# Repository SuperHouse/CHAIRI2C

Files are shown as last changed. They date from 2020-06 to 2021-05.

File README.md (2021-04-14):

Chair I2C Interface
===================
Copyright 2020 SuperHouse Automation Pty Ltd <www.superhouse.tv>  
Designed by Jonathan Oxer

Connects to a Permobil electric wheelchair controller, and emulates the
signals from a wheelchair joystick so that the chair can be controlled
electronically. Provides an I2C interface for connection to a host
microcontroller.

Also exposes the "5th Button" and 12V 100mA chair power connections.

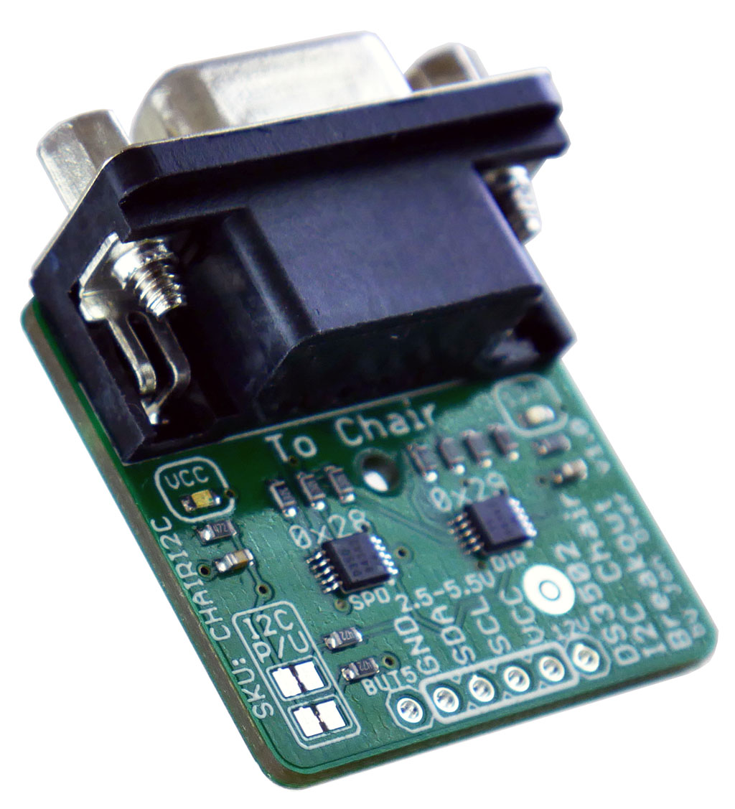
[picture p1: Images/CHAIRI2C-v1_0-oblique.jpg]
PCB


Features:

 * 1 x chair controller output.
 * I2C interface.
 * Derives 12V power from the host wheelchair controller.
 * Requires 2.7-5.5V external logic power.

More information is available at:

  http://www.superhouse.tv/chairi2c

INSTALLATION
------------
The design is saved as an EAGLE project. EAGLE PCB design software is
available from www.cadsoftusa.com free for non-commercial use. To use
this project download it and place the directory containing these files
into the "eagle" directory on your computer. Then open EAGLE and
navigate to the project.

DISTRIBUTION
------------
The specific terms of distribution of this project are governed by the
license referenced below.

LICENSE
-------
Licensed under the TAPR Open Hardware License (www.tapr.org/OHL).
The "license" folder within this repository also contains a copy of
this license in plain text format.

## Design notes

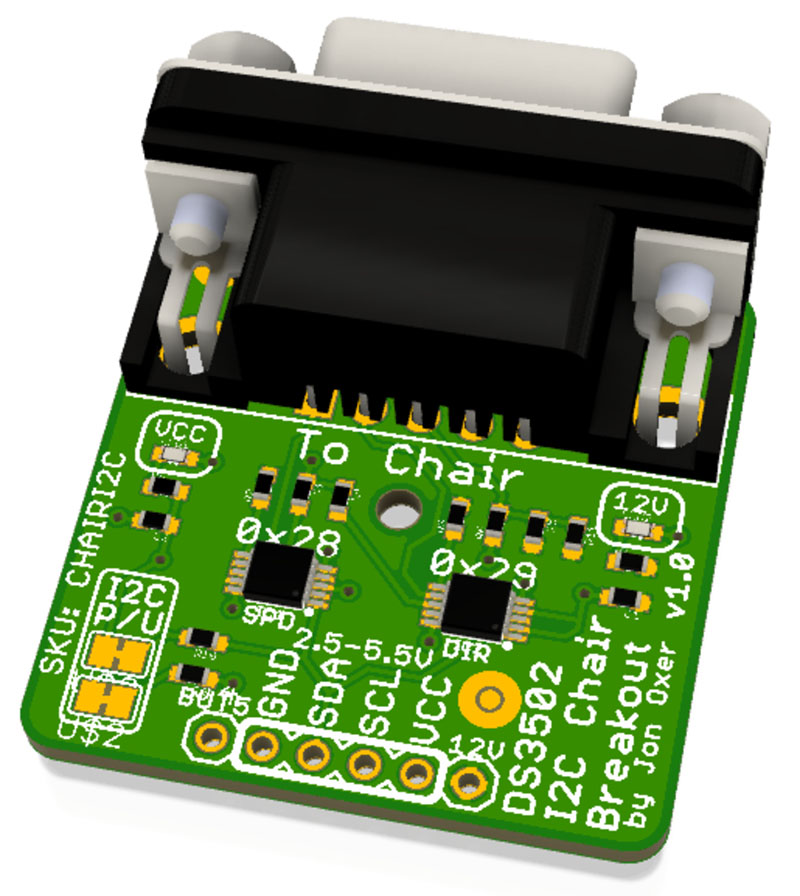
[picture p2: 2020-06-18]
Images/CHAIRI2C-v1_0-oblique-render.jpg

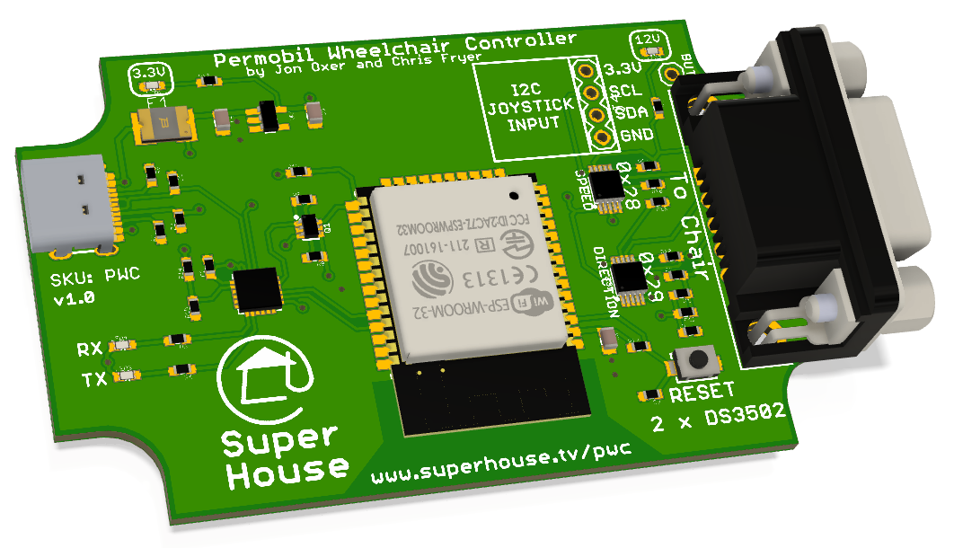
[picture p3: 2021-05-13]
Images/PWC-v1_0-render.png

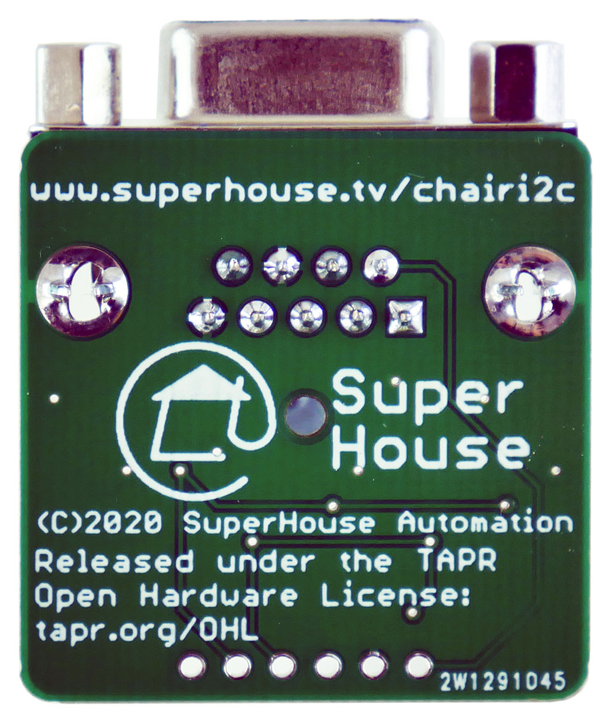
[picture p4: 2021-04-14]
Images/CHAIRI2C-v1_0-back.jpg

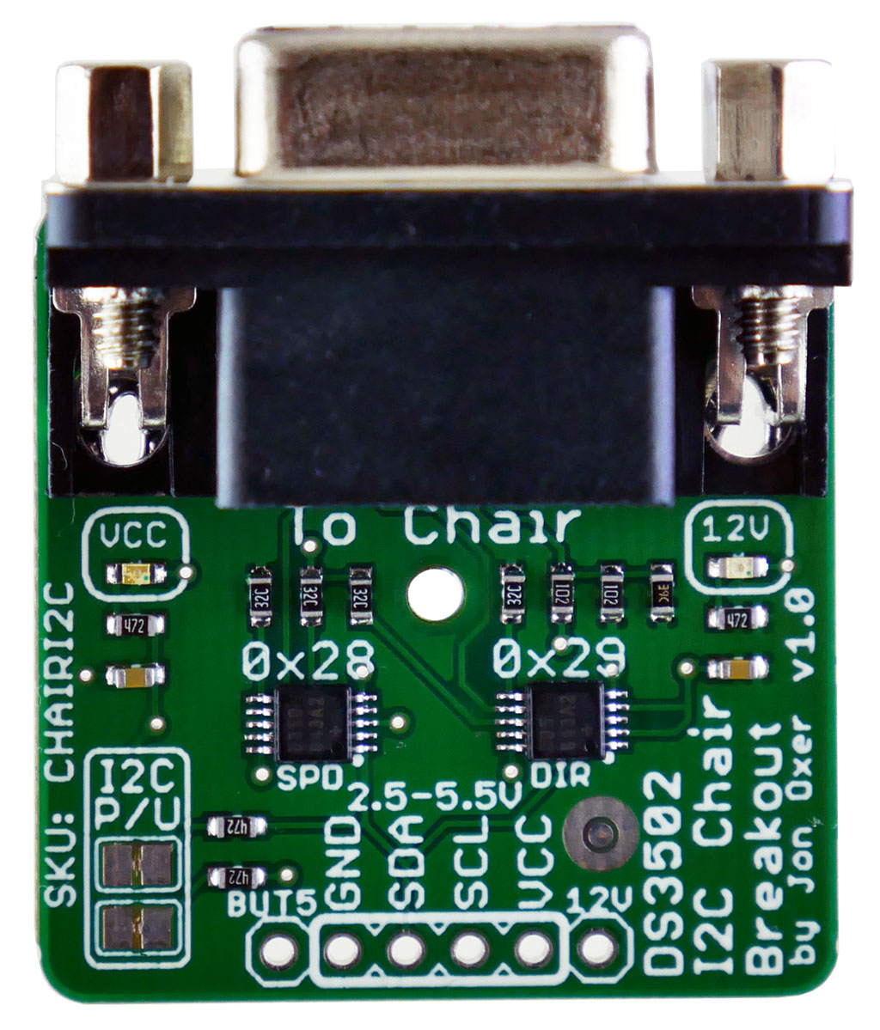
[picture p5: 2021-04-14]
Images/CHAIRI2C-v1_0-front.jpg

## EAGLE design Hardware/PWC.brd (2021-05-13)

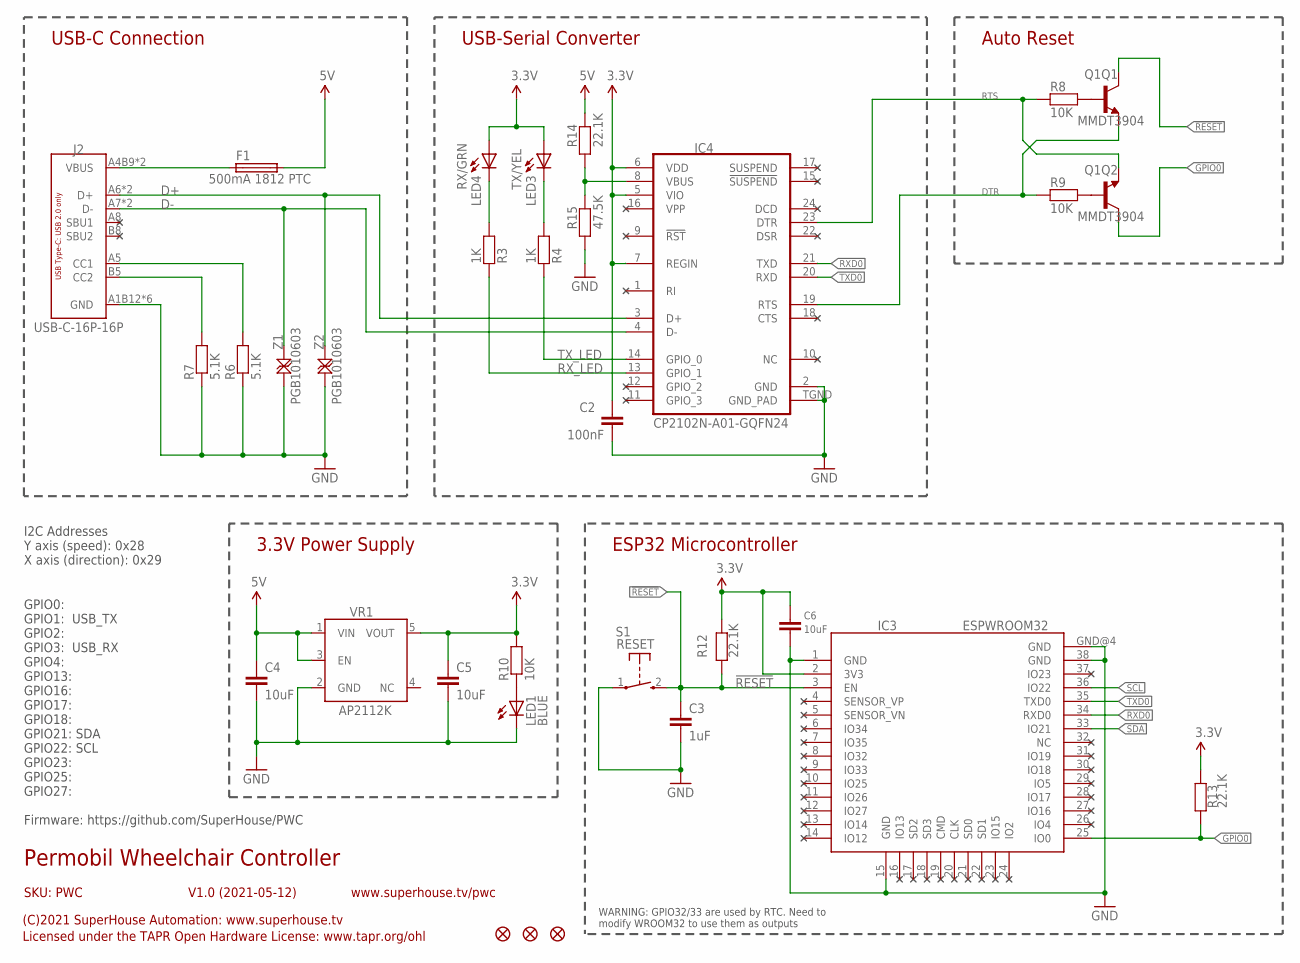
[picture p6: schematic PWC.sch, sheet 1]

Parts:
C2: 100nF; C0603
C3: 1uF; C0603
C4, C5, C6: 10uF; C0805
F1: 500mA 1812 PTC; 1812
IC3: ESPWROOM32
IC4: CP2102N-A01-GQFN24; QFN-24
J2: USB-C-16P-16P; USB-C-16P
LED1: BLUE; LED-0603
LED3: TX/YEL; LED-0603
LED4: RX/GRN; LED-0603
Q1: MMDT3904; SOT-363
R3, R4: 1K; R0603
R6, R7: 5.1K; R0603
R8, R9, R10: 10K; R0603
R12, R13, R14: 22.1K; R0603
R15: 47.5K; R0603
S1: RESET; TACTILE_SMT_3X4X2
U$35, U$36, U$37: FIDUCIAL1X2; FIDUCIAL-1X2
VR1: AP2112KSOT25; SOT23-5
Z1, Z2: PGB1010603; TVS0603

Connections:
3.3V: C2.1, C5.1, C6.1, IC3.2 (3V3), IC4.5 (VIO), IC4.6 (VDD), IC4.7 (REGIN), LED3.A, LED4.A, R10.2, R12.1, R13.1, VR1.5 (VOUT); also elsewhere on the board
5V: C4.1, F1.2, R14.2, VR1.1 (VIN), VR1.3 (EN)
!RESET: C3.1, IC3.3 (EN), Q1.3 (C), R12.2, S1.2 (S)
D+: IC4.3 (D+), J2.A6 (D+), J2.B6 (D+), Z2.2
D-: IC4.4 (D-), J2.A7 (D-), J2.B7 (D-), Z1.2
DTR: IC4.23 (DTR), Q1.1 (E), R8.1
GND: C2.2, C3.2, C4.2, C5.2, C6.2, IC3.1 (GND), IC3.15 (GND), IC3.38 (GND), IC3.GND@4 (GND), IC4.2 (GND), IC4.TGND (GND_PAD), J2.A1B12 (GND), J2.A12B1 (GND), J2.FIX1 (GND), J2.FIX2 (GND), J2.FIX3 (GND), J2.FIX4 (GND), LED1.C, R6.1, R7.1, R15.1, S1.1, VR1.2 (GND), Z1.1, Z2.1; also elsewhere on the board
GPIO0: IC3.25 (IO0), Q1.6 (C), R13.2
unnamed: LED1.A, R10.1
unnamed: Q1.5 (B), R8.2
unnamed: Q1.2 (B), R9.2
unnamed: LED4.C, R3.2
unnamed: J2.B5 (CC2), R7.2
unnamed: J2.A5 (CC1), R6.2
unnamed: LED3.C, R4.2
unnamed: IC4.8 (VBUS), R14.1, R15.2
RTS: IC4.19 (RTS), Q1.4 (E), R9.1
RXD0: IC3.34 (RXD0), IC4.21 (TXD)
RX_LED: IC4.13 (GPIO_1), R3.1
SCL: IC3.36 (IO22); also elsewhere on the board
SDA: IC3.33 (IO21); also elsewhere on the board
TXD0: IC3.35 (TXD0), IC4.20 (RXD)
TX_LED: IC4.14 (GPIO_0), R4.1
VIN: F1.1, J2.A4B9 (VBUS), J2.A9B4 (VBUS)

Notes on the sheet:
USB-C Connection
USB-Serial Converter
Auto Reset
3.3V Power Supply
ESP32 Microcontroller
WARNING: GPIO32/33 are used by RTC. Need to modify WROOM32 to use them as outputs
GPIO0: GPIO1: USB_TX GPIO2: GPIO3: USB_RX GPIO4: GPIO13: GPIO16: GPIO17: GPIO18: GPIO21: SDA GPIO22: SCL GPIO23: GPIO25: GPIO27: Firmware: https://github.com/SuperHouse/PWC
Permobil Wheelchair Controller
V1.0 (2021-05-12)
SKU: PWC
(C)2021 SuperHouse Automation: www.superhouse.tv
Licensed under the TAPR Open Hardware License: www.tapr.org/ohl
www.superhouse.tv/pwc
I2C Addresses Y axis (speed): 0x28 X axis (direction): 0x29

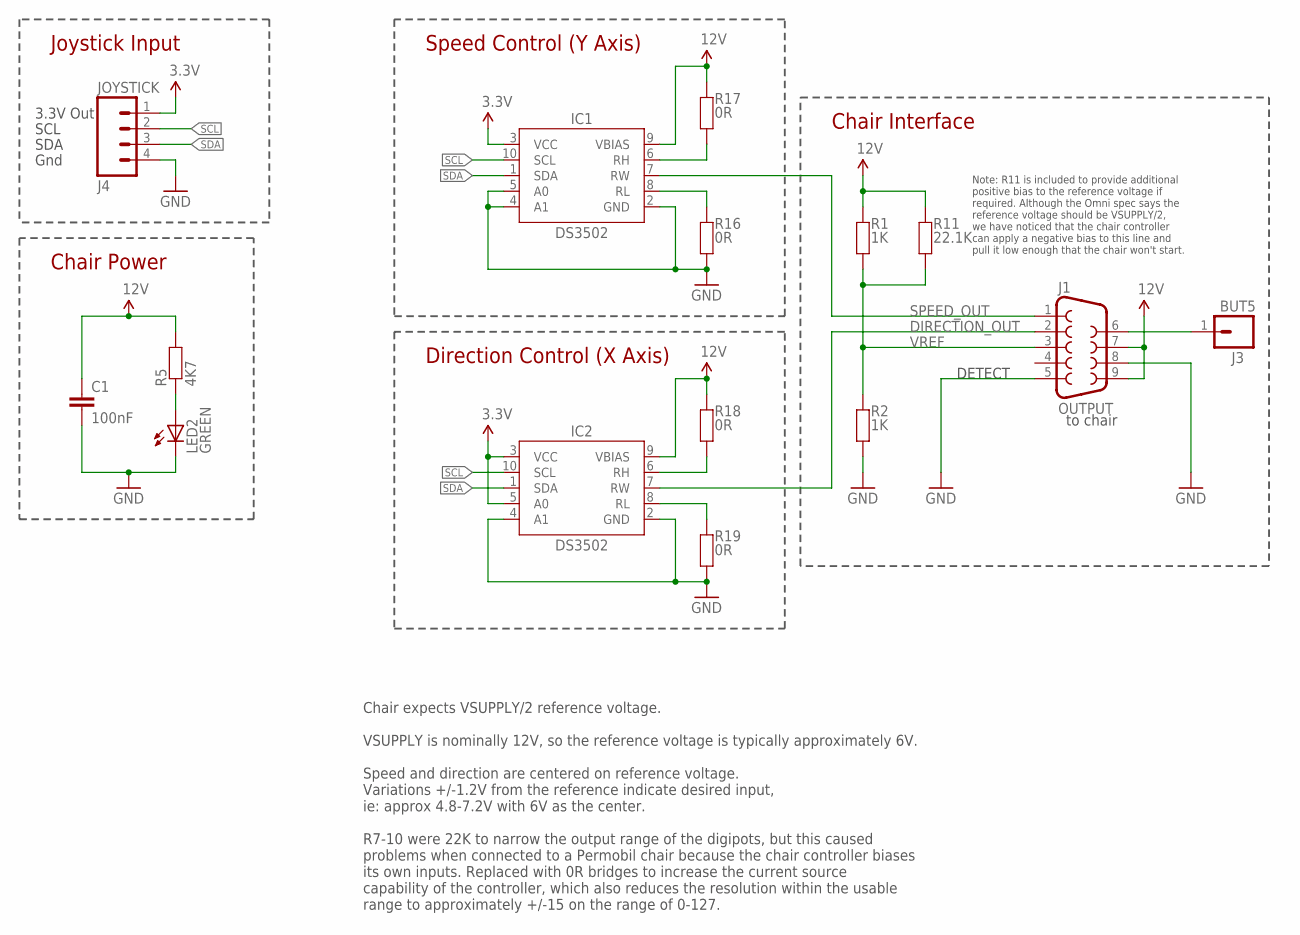
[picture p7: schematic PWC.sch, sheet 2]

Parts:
C1: 100nF; C0603
IC1, IC2: DS3502; MSOP10
J1: OUTPUT; DB9-PCB-SOCKET
J3: BUT5; 1X01
J4: JOYSTICK; 1X04
LED2: GREEN; LED-0603
R1, R2: 1K; R0603
R5: 4K7; R0603
R11: 22.1K; R0603
R16, R17, R18, R19: 0R; R0603

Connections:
3.3V: IC1.3 (VCC), IC2.3 (VCC), IC2.5 (A0), J4.1; also elsewhere on the board
12V: C1.1, IC1.9 (VBIAS), IC2.9 (VBIAS), J1.7, J1.9, R1.2, R5.2, R11.2, R17.2, R18.2
BUT5: J1.6, J3.1
DIRECTION_OUT: IC2.7 (RW), J1.2
GND: C1.2, IC1.2 (GND), IC1.4 (A1), IC1.5 (A0), IC2.2 (GND), IC2.4 (A1), J1.5, J1.8, J4.4, LED2.C, R2.1, R16.1, R19.1; also elsewhere on the board
unnamed: IC1.6 (RH), R17.1
unnamed: IC2.6 (RH), R18.1
unnamed: IC1.8 (RL), R16.2
unnamed: LED2.A, R5.1
unnamed: IC2.8 (RL), R19.2
SCL: IC1.10 (SCL), IC2.10 (SCL), J4.2; also elsewhere on the board
SDA: IC1.1 (SDA), IC2.1 (SDA), J4.3; also elsewhere on the board
SPEED_OUT: IC1.7 (RW), J1.1
VREF: J1.3, R1.1, R2.2, R11.1

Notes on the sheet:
to chair
Direction Control (X Axis)
Speed Control (Y Axis)
Chair Interface
Note: R11 is included to provide additional positive bias to the reference voltage if required. Although the Omni spec says the reference voltage should be VSUPPLY/2, we have noticed that the chair controller can apply a negative bias to this line and pull it low enough that the chair won't start.
DETECT
Chair Power
Chair expects VSUPPLY/2 reference voltage. VSUPPLY is nominally 12V, so the reference voltage is typically approximately 6V. Speed and direction are centered on reference voltage. Variations +/-1.2V from the reference indicate desired input, ie: approx 4.8-7.2V with 6V as the center. R7-10 were 22K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
Joystick Input
3.3V Out
SCL
SDA
Gnd

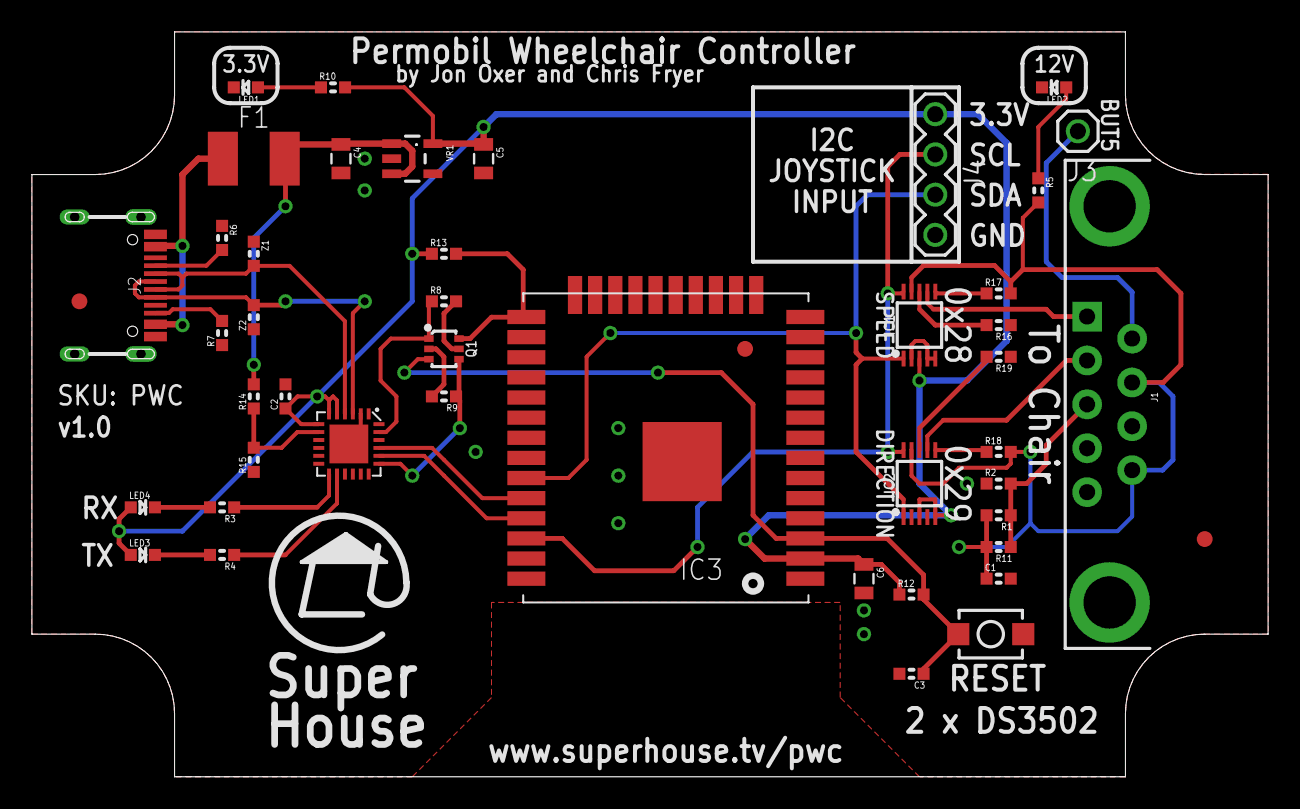
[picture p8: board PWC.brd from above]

Board: 2 copper layers, 78.0 x 47.0 mm, 46 parts (0 on the bottom side), 34 nets.

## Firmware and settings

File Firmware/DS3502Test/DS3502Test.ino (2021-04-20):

/**
   "Zero Deflection" Assistive Technology Joystick

   Internal dependencies. Install using Arduino library manager:
     "HX711_ADC" by Olav Kallhovd
   To do:
    -

   XIAO pin assignments:
     D0:
     D1:
     D2:
     D3:
     D4:  SDA
     D5:  SCL
     D6:  Tare pin
     D7:  Disable pin
     D8:
     D9:
     D10:

   227g (Pocophone) = 920000 reading

   By:
    Chris Fryer <chris.fryer78@gmail.com>
    Jonathan Oxer <jon@oxer.com.au>

   Copyright 2019-2020 SuperHouse Automation Pty Ltd www.superhouse.tv
*/
#define VERSION "2.2"
/*--------------------------- Configuration ---------------------------------*/
// Configuration should be done in the included file:
#include "config.h"

/*--------------------------- Libraries -------------------------------------*/
#include <HX711_ADC.h>              // Load cell amplifier
#include <Adafruit_DS3502.h>        // Digital potentiometer

/*--------------------------- Global Variables ------------------------------*/
uint32_t g_last_digipot_time     = 0;   // When we last updated the digipot outputs

uint8_t  g_left_button_state     = 0;
uint8_t  g_right_button_state    = 0;

/*--------------------------- Function Signatures ---------------------------*/
/*
  void     readInputPosition();
  int16_t  getScaledLoadCellValueX();
  int16_t  getScaledLoadCellValueY(); */

/*--------------------------- Instantiate Global Objects --------------------*/
Adafruit_DS3502 digipot_x = Adafruit_DS3502();
Adafruit_DS3502 digipot_y = Adafruit_DS3502();

/*--------------------------- Program ---------------------------------------*/
/**
  Setup
*/
void setup()
{
  Serial.begin(SERIAL_BAUD_RATE);
  //while (!Serial) {
  //  ; // wait for serial port to connect. Needed for native USB port only
  //}
  Serial.print("ZeroStick starting up, v");
  Serial.println(VERSION);

  pinMode(DISABLE_PIN,            INPUT_PULLUP);
  pinMode(TARE_BUTTON_PIN,        INPUT_PULLUP);
  pinMode(MOUSE_LEFT_BUTTON_PIN,  INPUT_PULLUP);
  pinMode(MOUSE_RIGHT_BUTTON_PIN, INPUT_PULLUP);

  if (!digipot_x.begin(DIGIPOT_X_I2C_ADDR)) {
    Serial.println("Couldn't find X-axis DS3502 chip");
  }
  Serial.println("Found X-axis DS3502 chip");

  if (!digipot_y.begin(DIGIPOT_Y_I2C_ADDR)) {
    Serial.println("Couldn't find Y-axis DS3502 chip");
  }
  Serial.println("Found Y-axis DS3502 chip");

  digipot_x.setWiper(65);               // Start with pots in central position
  digipot_y.setWiper(65);               // Start with pots in central position
}

/**
  Loop
*/
void loop()
{
  //updateDigipotOutputs();
}


/**

*/
void checkMouseButtons()
{
  uint8_t left_button_state = digitalRead(MOUSE_LEFT_BUTTON_PIN);
  if (LOW == left_button_state)
  {
    if (HIGH == g_left_button_state)
    {
      
      Serial.println("down");
      g_left_button_state = LOW;
    }
  }
  if (HIGH == left_button_state)
  {
    if (LOW == g_left_button_state)
    {
      
      Serial.println("up");
      g_left_button_state = HIGH;
    }
  }

  uint8_t right_button_state = digitalRead(MOUSE_RIGHT_BUTTON_PIN);
  if (LOW == right_button_state)
  {
    if (HIGH == g_right_button_state)
    {
      
      Serial.println("down");
      g_right_button_state = LOW;
    }
  }
  if (HIGH == right_button_state)
  {
    if (LOW == g_right_button_state)
    {
      
      Serial.println("up");
      g_right_button_state = HIGH;
    }
  }
}


/**
  Send mouse movements to the wheelchair
*/
void updateDigipotOutputs()
{
#if ENABLE_DIGIPOT_OUTPUT
  if (digitalRead(DISABLE_PIN) == HIGH) // Pull this pin low to disable
  {
    if (millis() > g_last_digipot_time + DIGIPOT_INTERVAL)
    {
      int8_t pot_position_x = 63 + (int)(g_pressure_level_x);
      int8_t pot_position_y = 63 + (int)(g_pressure_level_y);
      digipot_x.setWiper(pot_position_x);
      digipot_y.setWiper(pot_position_y);

      Serial.print("X: ");
      Serial.print(pot_position_x);
      Serial.print("    Y: ");
      Serial.println(pot_position_y);
      g_last_digipot_time = millis();
    }
  }
#endif
}

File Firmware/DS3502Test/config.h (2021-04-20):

/* ----------------- General config -------------------------------- */
/* Output options */
#define   ENABLE_SERIAL_DEBUGGING true

/* Serial */
#define     SERIAL_BAUD_RATE     115200  // Speed for USB serial console

/* ----------------- Hardware-specific config ---------------------- */
/*
   The hardware config for this project depends on a variable set by the
   Arduino environment to detect the target board type. Currently only
   2 target boards are supported: Arduino Leonardo, and Seeeduino XIAO.

   Update the pin definitions in the section for your target board.

   This board detection method is also used in the program to load a
   different HID library and configure it differently depending on the
   board type. If using a Seeeduino XIAO, you must select Tools ->
   USB Stack -> TinyUSB.
*/

/**** Pins for Seeeduino XIAO ****/
/* Inputs */
#define   TARE_BUTTON_PIN             6  // Pull this pin to GND to tare
#define   DISABLE_PIN                 7  // Pull this pin to GND to disable
#define   MOUSE_LEFT_BUTTON_PIN       8  // Pull this pin to GND for left click
#define   MOUSE_RIGHT_BUTTON_PIN      9  // Pull this pin to GND for right click
/**** End of XIAO pins ****/

/* I2C addresses */
#define   DIGIPOT_X_I2C_ADDR       0x28
#define   DIGIPOT_Y_I2C_ADDR       0x29

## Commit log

2020-06-05 Import of first rough draft
    [CHAIRI2C.brd, CHAIRI2C.sch]
2020-06-09 Changed VREF on digital pots for v1.0 release
    [CHAIRI2C.brd, CHAIRI2C.sch]
2020-06-18 Changed reference bias and exposed extra connections
    [CHAIRI2C.brd, CHAIRI2C.sch]
2021-04-13 Moved existing project files into directories.
    [CHAIRI2C.brd, CHAIRI2C.sch]
2021-04-14 Changed I2C pullups from 10K to 4K7. Moved designators to improve readability.
    [CHAIRI2C.brd, CHAIRI2C.sch]
2021-04-14 Renumbered parts to simplify production setup.
    [CHAIRI2C.brd, CHAIRI2C.sch]
2021-04-14 Added images of prototype.
2021-04-20 Changed output range resistors from 22K to 0R.
    [CHAIRI2C.brd, CHAIRI2C.sch]
2021-05-11 Forked board files to make version with carrier for XIAO.
    [CHAIRI2CXIAO.brd, CHAIRI2CXIAO.sch]
2021-05-12 Major conversion to use ESP32 in UB5 plastic box.
    [CHAIRI2CXIAO.brd, CHAIRI2CXIAO.sch]
2021-05-12 Renamed project files for Permobil version.
    [PWC.brd, PWC.sch]
2021-05-13 Routing, silkscreen, designators, ERC / DRC for v1.0 release.
    [PWC.brd, PWC.sch]
2021-05-13 Added render of PWC v1.0 board.
